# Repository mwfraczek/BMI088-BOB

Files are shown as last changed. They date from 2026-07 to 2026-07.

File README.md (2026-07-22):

# BMI088 Custom Breakout Board

IMG_5351(1)

## Design Overview:
Designed as a first PCB layout project and hand-assembled via hotplate reflow. Built to test IMU functionality and to integrate into a thrust vector control (TVC) gimbal control loop. Existing domestic BMI088 breakouts either require expensive application boards to interface with, or expose only I²C. This design breaks out both I²C and SPI, with components selected in part for domestic sourcing and tariff avoidance. Full assembly process shown in link below:

https://youtube.com/shorts/Hh-Zr3-ZTfY?feature=share

- **Schematic:** 



- **Board layout:** 

Screenshot from 2026-05-26 21-09-24

## Features:
- Onboard 3.3V LDO — Vin tolerant from 3.3 V to 6 V
- I²C and SPI accessible via standard 2.54mm pin headers
- Power indicator LED

## Bill of Materials:
| Ref | Package | Part | Qty |
|-----|---|---|-----|
| U1 | LGA-16 | Bosch BMI088 IMU | 1 |
| U2 | SOT-23 | MCP1700-3302 LDO | 1 |
| C1–C2 | 0402 | 0.1 µF | 2 |
| C3–C4 | 0603 | 0.1 µF | 2 |
| R1–R2 | 0603 | 4.7 kΩ (I²C pull-ups) | 2 |
| R3 | 0603 | 2.2 kΩ | 1 |
| R4 | 0603 | 10 kΩ | 1 |
| D2 | 0603 | LED | 1 |

## Repository Structure:
- `hardware/` — KiCad project files (schematic, PCB layout)
- `gerbers/` — Manufacturing files (Gerbers, drill files) ready to send to a fab

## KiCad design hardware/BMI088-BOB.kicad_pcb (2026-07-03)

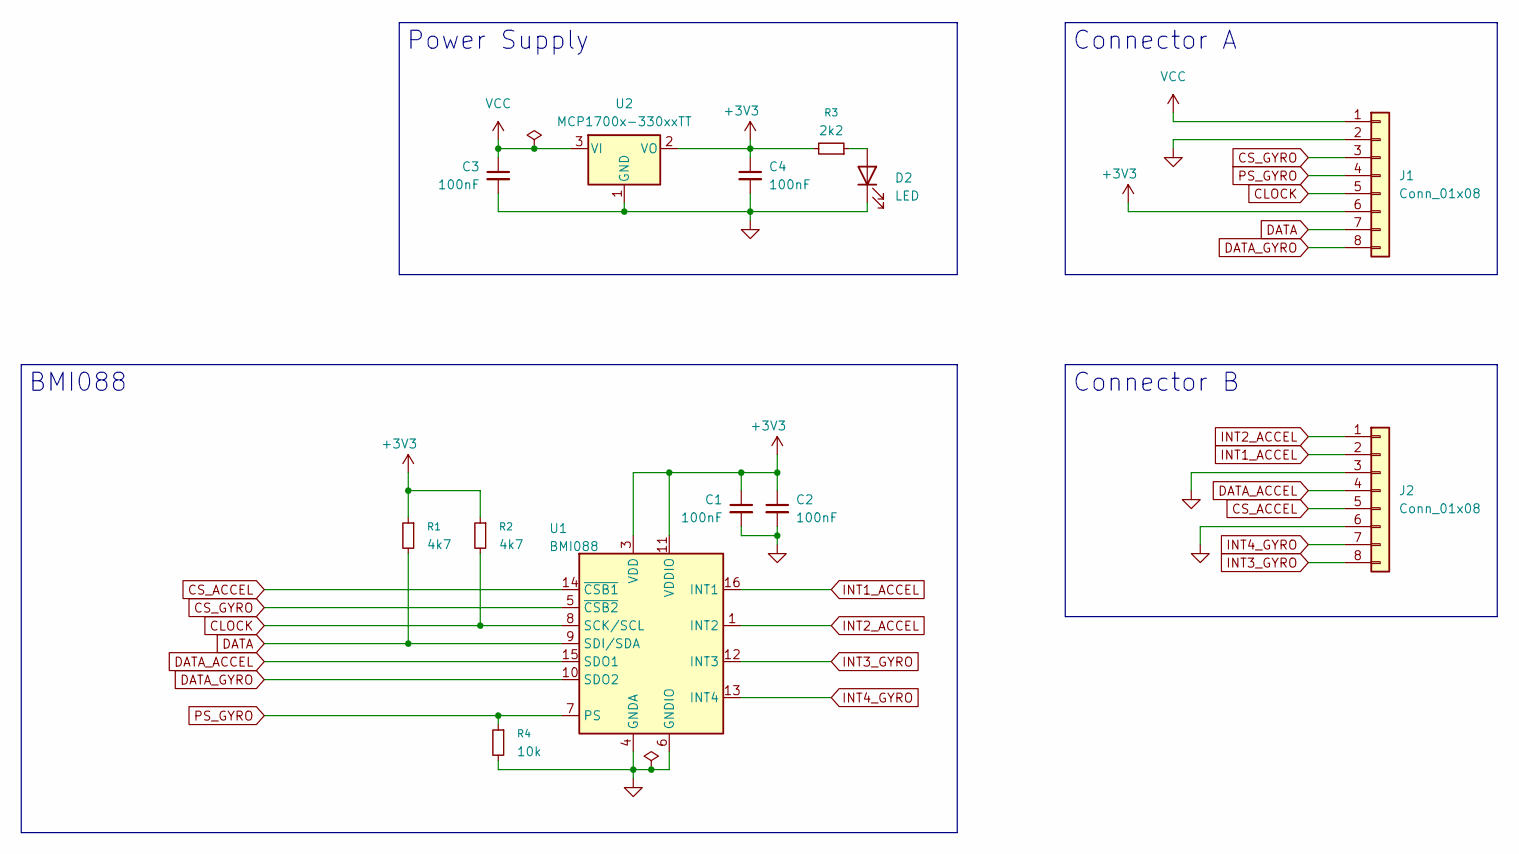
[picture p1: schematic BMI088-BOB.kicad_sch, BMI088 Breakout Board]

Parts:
C1, C2: 100nF; C_0402_1005Metric
C3, C4: 100nF; C_0603_1608Metric
D2: LED; LED_0603_1608Metric
J1, J2: Conn_01x08; PinHeader_1x08_P2.54mm_Vertical
R1, R2: 4k7; R_0603_1608Metric
R3: 2k2; R_0603_1608Metric
R4: 10k; R_0603_1608Metric
U1: BMI088; Bosch_LGA-16_4.5x3mm_P0.5mm_LayoutBorder7x1y_ClockwisePinNu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
U2: MCP1700x-330xxTT; SOT-23

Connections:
+3V3: C1.1, C2.1, C4.1, J1.6, R1.1, R2.1, R3.2, U1.3 (VDD), U1.11 (VDDIO), U2.2 (VO)
CLOCK: J1.5, R2.2, U1.8 (SCK/SCL)
CS_ACCEL: J2.5, U1.14 (~CSB1)
CS_GYRO: J1.3, U1.5 (~CSB2)
DATA: J1.7, R1.2, U1.9 (SDI/SDA)
DATA_ACCEL: J2.4, U1.15 (SDO1)
DATA_GYRO: J1.8, U1.10 (SDO2)
GND: C1.2, C2.2, C3.2, C4.2, D2.1 (K), J1.2, J2.3, J2.6, R4.2, U1.2 (GNDA), U1.4 (GNDA), U1.6 (GNDIO), U2.1 (GND)
INT1_ACCEL: J2.2, U1.16 (INT1)
INT2_ACCEL: J2.1, U1.1 (INT2)
INT3_GYRO: J2.8, U1.12 (INT3)
INT4_GYRO: J2.7, U1.13 (INT4)
unnamed: D2.2 (A), R3.1
PS_GYRO: J1.4, R4.1, U1.7 (PS)
VCC: C3.1, J1.1, U2.3 (VI)

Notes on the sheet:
Connector B
Connector A
Power Supply
BMI088

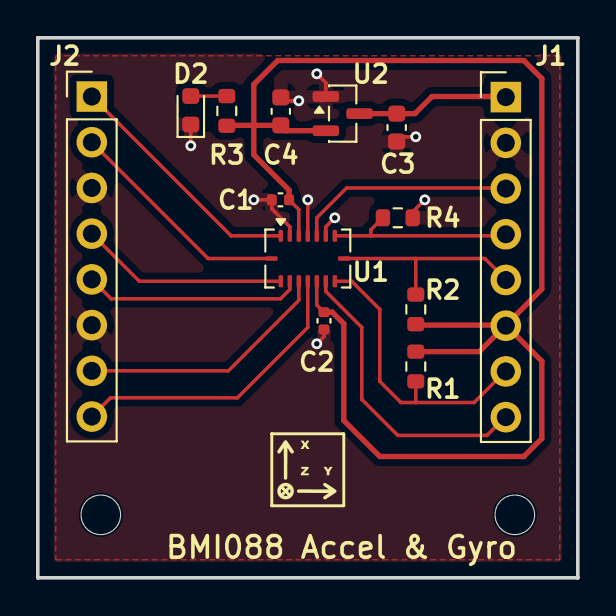
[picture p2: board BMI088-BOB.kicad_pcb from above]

Board: 2 copper layers, 30.0 x 30.0 mm, 13 parts (0 on the bottom side), 15 nets.
